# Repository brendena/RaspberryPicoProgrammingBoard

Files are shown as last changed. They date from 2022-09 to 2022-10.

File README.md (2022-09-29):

# boards
## PicoProbeProgrammerBoard

A board to help with programming and debugging the raspberry pi pico.  I have a standard 2x5 pin connector that can carry swd, power and some extra debug signals

connectors 
* 1.27mm 2x5 Pin 10 Pin SMT
* 2.54mm 7 pin breakout jtag
* 3 1.0mm jst connector - used on the pico with that comes pre soldiered

## PicoDebugInterface

This is a small board that sites ontop of the main raspberry pi pico to add a 2x5 pin connector ontop to make it easier to program with the option to add extra debug pin as well.

# RaspberryPi_PicoProgrammer

This board will make programming the pico a little cleaner.  It shares most of the features that the PicoProbeProgrammerBoard has.  But with the added benifit have being able to directly read the i2c's or debug connections while directly from the pi.

* Potentially very usfull with a right angle for the pi 4000.  So you can easily add debugging ability to that board.

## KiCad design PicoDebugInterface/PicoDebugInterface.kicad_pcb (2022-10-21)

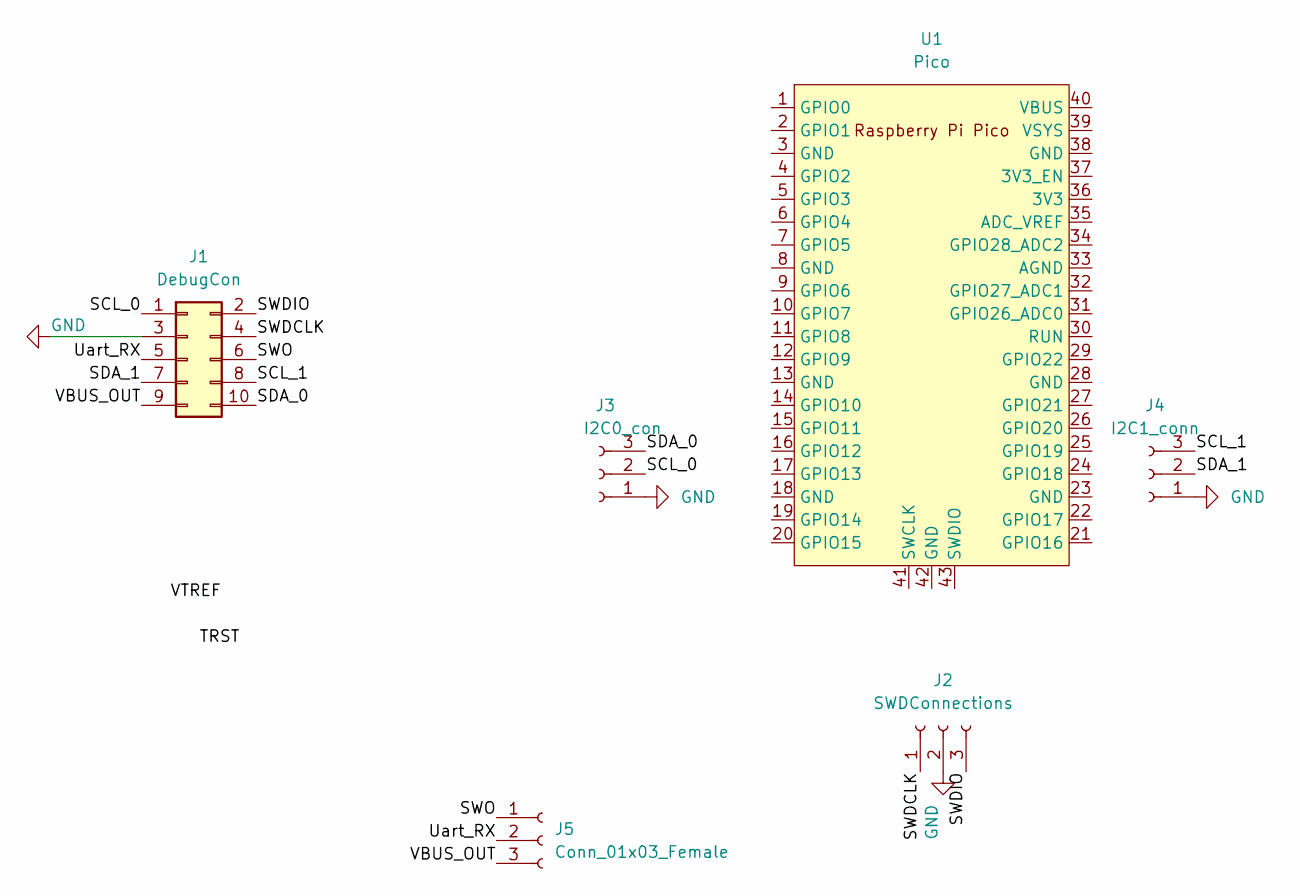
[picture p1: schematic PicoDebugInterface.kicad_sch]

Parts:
J1: DebugCon; 3220-10-0300-00-TR
J2: SWDConnections; BottomSWDConnection
J3: I2C0_con; BottomSWDConnection
J4: I2C1_conn; BottomSWDConnection
J5: Conn_01x03_Female; BottomSWDConnection
U1: Pico; RPi_Pico_SMD_TH

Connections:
/SCL_0: J1.1, J3.2
/SCL_1: J1.8, J4.3
/SDA_0: J1.10, J3.3
/SDA_1: J1.7, J4.2
/SWDCLK: J1.4, J2.1
/SWDIO: J1.2, J2.3
/SWO: J1.6, J5.1
/Uart_RX: J1.5, J5.2
/VBUS_OUT: J1.9, J5.3
GND: J1.3, J2.2, J3.1, J4.1

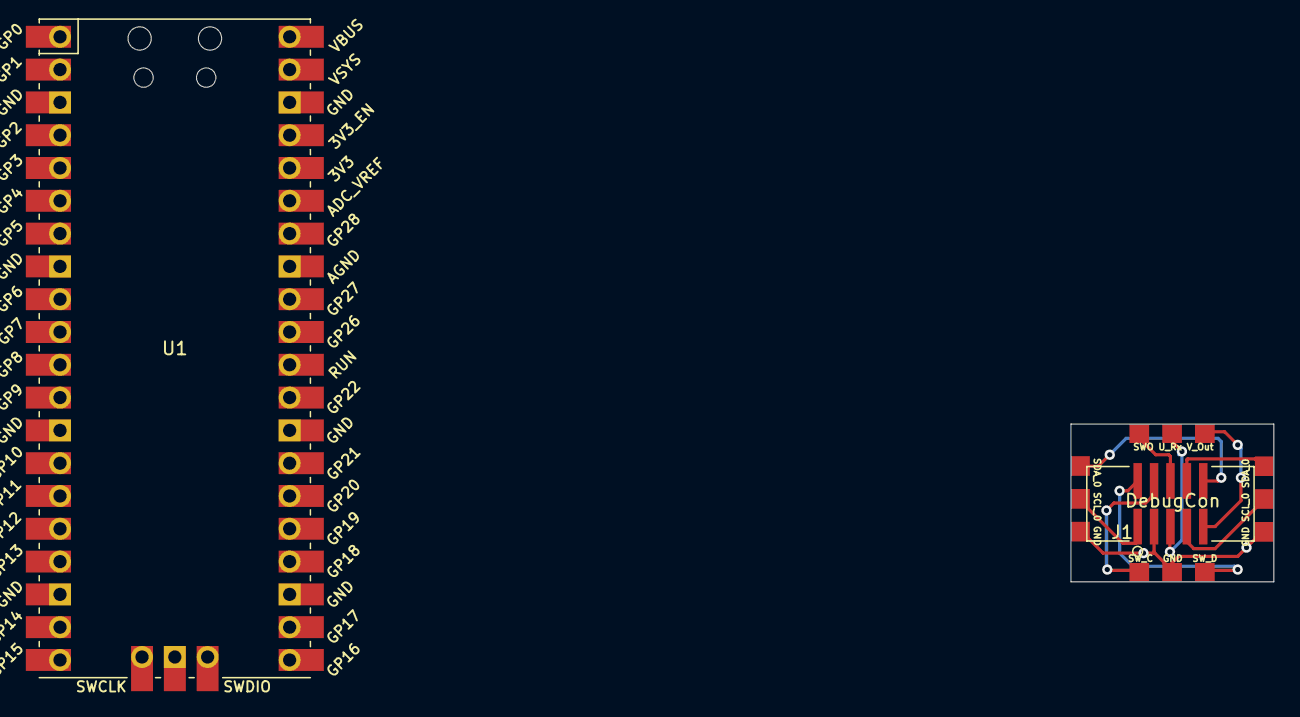
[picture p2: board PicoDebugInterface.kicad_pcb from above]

Board: 2 copper layers, 15.7 x 12.2 mm, 6 parts (0 on the bottom side), 10 nets.

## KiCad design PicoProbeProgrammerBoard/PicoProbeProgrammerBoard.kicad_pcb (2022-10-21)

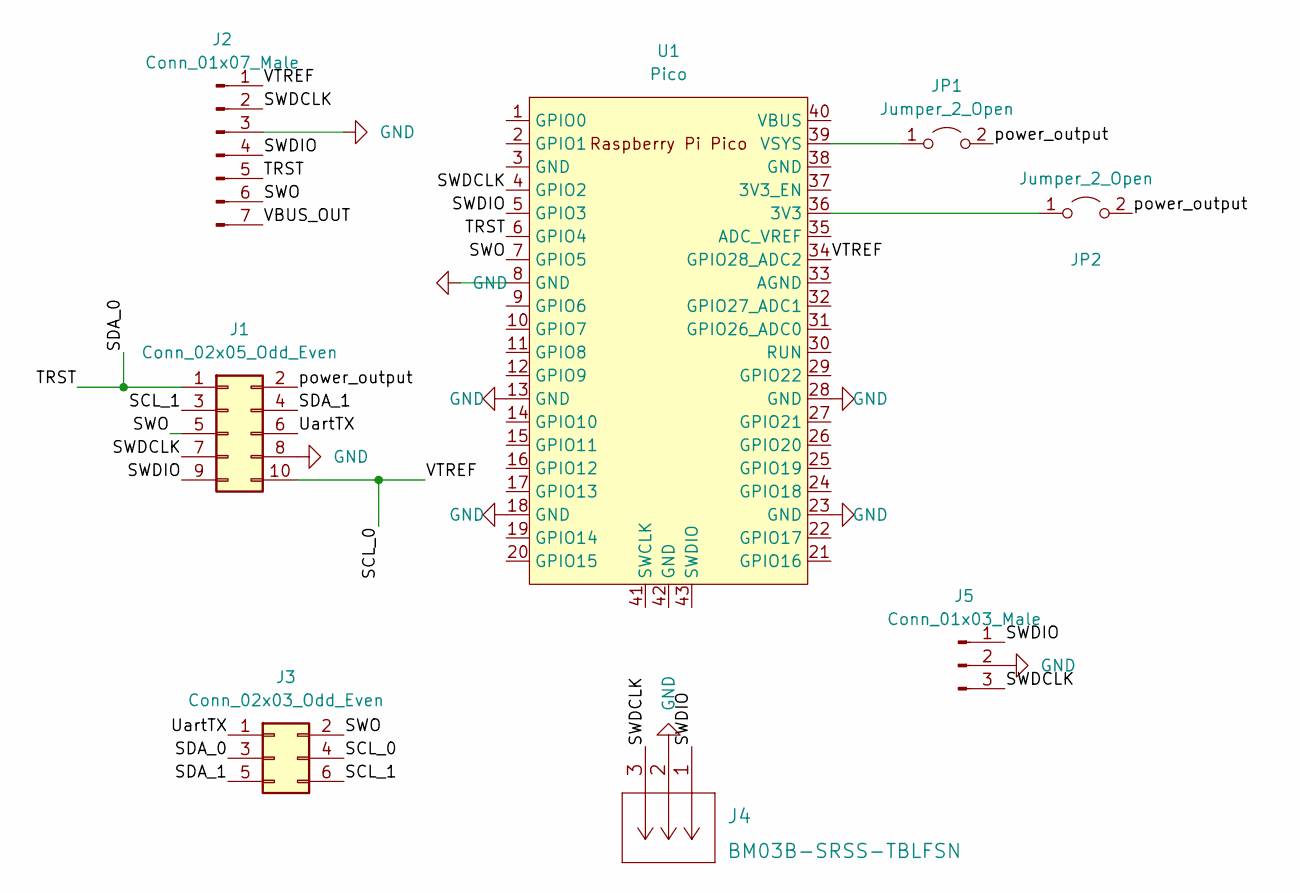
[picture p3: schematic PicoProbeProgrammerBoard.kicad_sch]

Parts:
J1: Conn_02x05_Odd_Even; 3220-10-0300-00-TR
J2: Conn_01x07_Male; PinSocket_1x07_P2.54mm_Horizontal
J3: Conn_02x03_Odd_Even; PinSocket_2x03_P2.54mm_Vertical
J4: BM03B-SRSS-TBLFSN
J5: Conn_01x03_Male; PinSocket_1x03_P2.54mm_Vertical
JP1, JP2: Jumper_2_Open; PinHeader_1x02_P2.54mm_Vertical
U1: Pico; RPi_Pico_SMD_TH

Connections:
/SCL_0: J1.10, J2.1, J3.4, U1.34 (GPIO28_ADC2)
/SCL_1: J1.3, J3.6
/SDA_0: J1.1, J2.5, J3.3, U1.6 (GPIO4)
/SDA_1: J1.4, J3.5
/SWDCLK: J1.7, J2.2, J4.3, J5.3, U1.4 (GPIO2)
/SWDIO: J1.9, J2.4, J4.1, J5.1, U1.5 (GPIO3)
/SWO: J1.5, J2.6, J3.2, U1.7 (GPIO5)
/UartTX: J1.6, J3.1
/VBUS_OUT: J2.7
/power_output: J1.2, JP1.2 (B), JP2.2 (B)
GND: J1.8, J2.3, J4.2, J5.2, U1.8 (GND), U1.13 (GND), U1.18 (GND), U1.23 (GND), U1.28 (GND)
unnamed: JP1.1 (A), U1.39 (VSYS)
unnamed: JP2.1 (A), U1.36 (3V3)

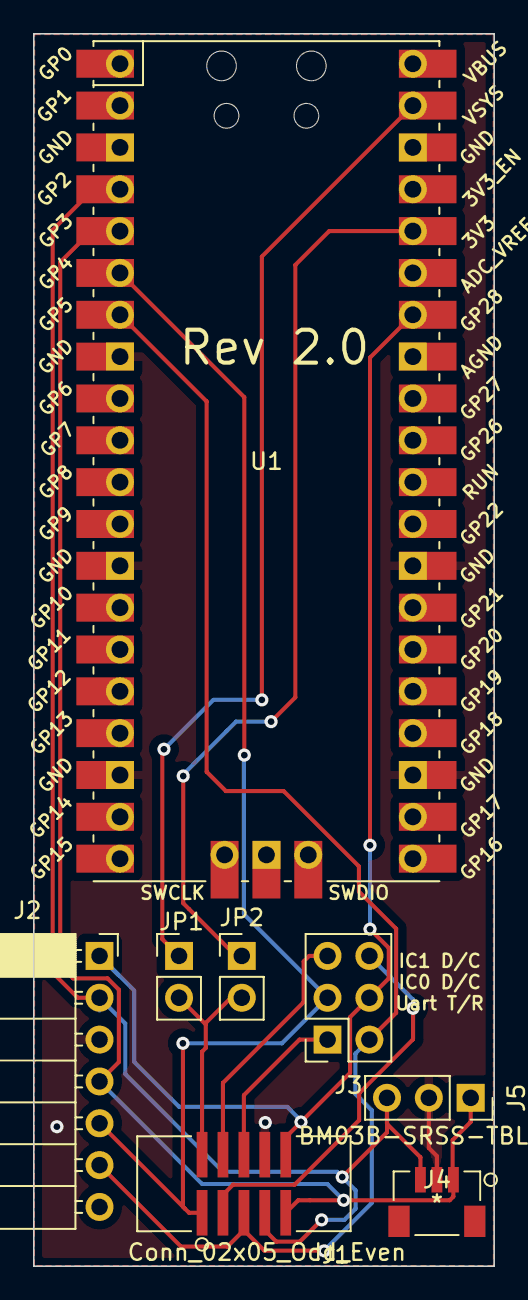
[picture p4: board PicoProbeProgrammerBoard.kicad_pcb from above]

Board: 2 copper layers, 27.9 x 74.8 mm, 8 parts (0 on the bottom side), 12 nets.

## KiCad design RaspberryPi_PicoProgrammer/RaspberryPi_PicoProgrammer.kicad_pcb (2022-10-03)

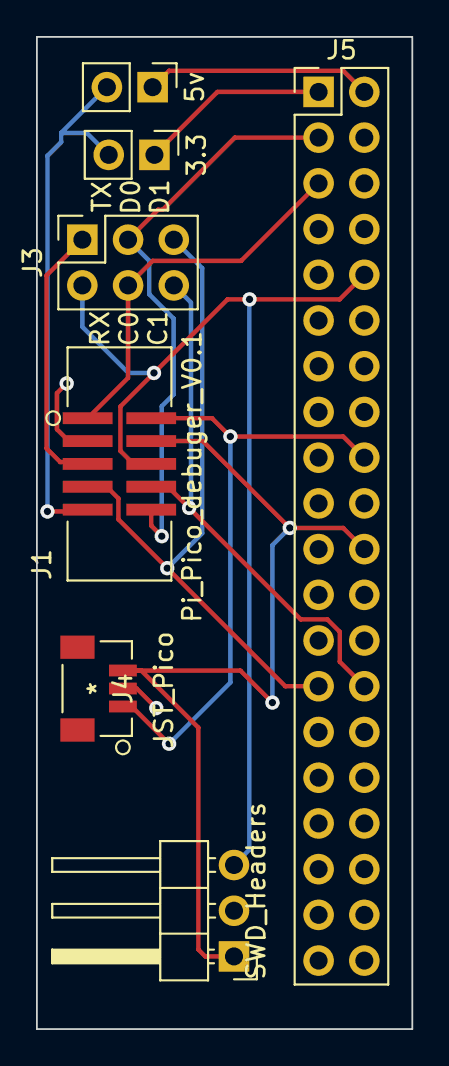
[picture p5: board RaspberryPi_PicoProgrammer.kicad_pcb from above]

Board: 2 copper layers, 20.9 x 55.1 mm, 7 parts (0 on the bottom side), 12 nets.

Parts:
3.3, 5v: Jumper_2_Open; PinHeader_1x02_P2.54mm_Vertical
J1: Pi_Pico_debuger_V0.1; 3220-10-0300-00-TR
J3: Conn_Extra; PinSocket_2x03_P2.54mm_Vertical
J4: JST_Pico; BM03B-SRSS-TBLFSN
J5: Raspberry_Pi_2_3; PinHeader_2x20_P2.54mm_Vertical
SWD_Headers: Conn_01x03_Male; PinHeader_1x03_P2.54mm_Horizontal

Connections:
/SCL_0: J1.1, J3.4, J5.5 (SCL/GPIO3)
/SCL_1: J1.8, J3.6, J5.28 (ID_SC/GPIO1)
/SDA_0: J1.10, J3.3, J5.3 (SDA/GPIO2)
/SDA_1: J1.7, J3.5, J5.27 (ID_SD/GPIO0)
/SWDCLK: J1.4, J4.3, J5.22 (GPIO25), SWD_Headers.1
/SWDIO: J1.2, J4.1, J5.18 (GPIO24)
/SWO: J1.6, J3.2, J5.10 (GPIO15/RXD), SWD_Headers.3
/UartTX: J1.5, J3.1, J5.8 (GPIO14/TXD)
/power_output: 3.3.2 (B), 5v.2 (B), J1.9
GND: J1.3, J4.2, J5.6 (GND), J5.9 (GND), J5.14 (GND), J5.20 (GND), J5.25 (GND), J5.30 (GND), J5.34 (GND), J5.39 (GND), SWD_Headers.2
unnamed: 3.3.1 (A), J5.1 (3V3)
unnamed: 5v.1 (A), J5.2 (5V)

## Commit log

2022-09-28 added boards
2022-09-28 added the actuall boards
    [PicoDebugInterface.kicad_pcb, PicoDebugInterface.kicad_sch, PicoProbeProgrammingBoard.kicad_pcb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]
2022-09-28 added layout
    [PicoDebugInterface.kicad_pcb, PicoDebugInterface.kicad_sch, PicoProbeProgrammerBoard.kicad_pcb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]
2022-09-29 added schematic for raspberry pi
    [PicoProbeProgrammerBoard.kicad_pcb, PinOutConnectorProgrammer - Sheet1.csv, RaspberryPi_PicoProgrammer.kicad_pcb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]
2022-10-02 almost done the board layout
    [PicoDebugInterface.kicad_pcb, PicoDebugInterface.kicad_sch, PicoProbeProgrammerBoard.kicad_pcb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]
2022-10-03 board sent out
    [PicoDebugInterface-B_Cu.gbr, PicoDebugInterface-B_Mask.gbr, PicoDebugInterface-B_Paste.gbr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]
2022-10-19 stuff submitted for 1 ref
    [PicoDebugInterface-B_Cu.gbr, PicoDebugInterface-B_Mask.gbr, PicoDebugInterface-B_Paste.gbr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]
2022-10-21 pushed fix for the connector so it a staight through cable
    [PicoDebugInterface.kicad_pcb, PicoDebugInterface.kicad_sch, PicoProbeProgrammerBoard.kicad_pcb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]

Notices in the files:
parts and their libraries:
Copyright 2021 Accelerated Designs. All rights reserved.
